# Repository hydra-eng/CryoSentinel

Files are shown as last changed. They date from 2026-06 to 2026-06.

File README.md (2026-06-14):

# Cryo Sentinel — Intelligent Cold Chain Auditing & Real-Time Telemetry






Cryo Sentinel is an industrial-grade, tamper-resistant cold chain tracking device that provides real-time environmental monitoring, cryptographic proof of custody, active physical breach detection, and adaptive wireless alerting. Designed for high-value logistics—including temperature-sensitive biopharmaceuticals, clinical trial assets, and critical cargo—Cryo Sentinel transforms cargo logging from passive historical recording to active real-time intervention.

---

## The Cryo Sentinel Advantage

In traditional cold chain logistics, temperature breaches are discovered only at the destination when the logger is plugged into a USB port. At that stage, the entire shipment is already spoiled, resulting in substantial financial losses and public health risks. 

Cryo Sentinel bridges this gap by combining continuous local logging, real-time wireless alerts, cryptographic integrity verification, and zero-power NFC configuration capabilities.

### Industry Comparison

| Feature | Traditional USB Loggers (e.g. TempTale) | Cryo Sentinel |
| :--- | :--- | :--- |
| **Alert Timing** | Post-arrival review (Passive) | Real-time mid-route alerting (Active) |
| **Wireless Range** | USB only or short-range NFC (≤10 cm) | LoRa SX1262 Long Range (Up to 15 km) |
| **Breach Location** | Unknown (discovered at destination) | GPS-Tagged (u-blox MAX-M10S) |
| **Data Integrity** | None (plaintext CSV/PDF logs can be falsified) | Hardware-chained SHA-256 Ledger (ATECC608A signed) |
| **Configuration** | Flashing / factory pre-set configuration | Zero-Power mobile configuration via Dynamic NFC |
| **Tamper Detection** | None (enclosures can be opened undetected) | Active physical loop (GPIO0 trace cut detection) |
| **User Interface** | Flashing status LEDs | 1.54" Zero-Power E-Ink status dashboard |
| **Power System** | Non-rechargeable coin cell (disposable) | LiPo rechargeable + USB-C + RF Energy Harvesting |

---

## Advanced Industrial Capabilities

### 1. Cryptographic Hash-Chaining Ledger
To prevent transit log falsification, Cryo Sentinel implements an onboard cryptographically-secured audit trail. Each new environmental log entry is hashed along with the SHA-256 signature of the preceding entry:
$$\text{Hash}_{n} = \text{SHA256}(\text{LogData}_{n} \parallel \text{Hash}_{n-1})$$
The ATECC608A secure element signs the latest running hash using ECDSA P-256, sealing the log history. Any retrospective editing of historical temperature readings instantly breaks the cryptographic chain.

### 2. Zero-Power NFC Configuration Write-Back
Operators can dynamically update environmental thresholds (e.g., temperature limits, sampling intervals) before sealing the container. Utilizing the ST25DV Dynamic NFC tag, the MCU parses incoming NDEF configuration profiles written by a mobile app on boot. This allows zero-power provisioning without opening the enclosure or plugging in USB cables.

### 3. Adaptive LoRa Telemetry & Buffer Queuing
To handle signal dead zones (such as tunnels or rural transit corridors), the firmware implements an alert transmission queue in the SPI flash. If a LoRa uplink fails, the alert is buffered locally. Once the device re-establishes connectivity, it automatically batches and transmits the queued timeline events.

### 4. GPS Hot-Start Optimization
The u-blox MAX-M10S is configured to store satellite ephemeris data using its backup battery power domain. In sampling mode, the warm-start logic reduces the Time-To-First-Fix (TTFF) from a 30-second cold start to under 2 seconds, minimizing high-current state durations and boosting battery life by up to 40%.

### 5. RF Energy Harvesting Power Recovery
The ST25DV Dynamic NFC Tag harvests RF power from a smartphone's NFC field, providing up to 5mA at 3.3V through its energy-harvesting pin (`V_EH`). If the primary LiPo battery dies mid-transit, operators can still read out the complete SHA-256 ledger using a phone, running entirely on harvested RF energy.

---

## Zen Engineering & Industrial Design

Cryo Sentinel follows four core tenets of industrial design harmony and engineering precision:

* **Minimalism in Energy (Active Rail Power-Gating)**: The environmental sensors (SHT40, ADXL345) and the u-blox MAX-M10S GPS are connected to a dedicated 3.3V power rail controlled by a P-channel MOSFET switch (DMG2305UX). During deep sleep (`STATE_IDLE`), the MCU cuts the rail entirely, reducing quiescent leakage current across all peripherals to under 1µA.
* **Environmental Resilience (Gore-Tex Equalization Vent)**: To measure temperature and humidity accurately, the device enclosure features a dual-purpose Gore pressure equalization vent. This allows ambient moisture and temperature gradients to balance quickly without exposing the main PCB layout to liquid water or dust, achieving an IP67 rating.
* **Dual RF Coplanar Waveguide Design**: The LoRa (865 MHz) and GPS RF lines are routed using grounded coplanar waveguides designed with a target 50-ohm characteristic impedance on a standard 1.6mm FR-4 substrate. This prevents RF signal attenuation and harmonic cross-talk between high-frequency GPS and LoRa transceivers.
* **Dual-State Dynamic NFC Interfacing**: When the primary battery is healthy, the tag acts as an active mailbox, serving real-time parameters. When the battery is drained, the tag switches to passive mode, drawing energy from a scanning device to feed audit details from non-volatile EEPROM.

---

## System Architecture

### Hardware Block Diagram

```mermaid
graph LR
    classDef mcu fill:#1a1a1a,stroke:#4CAF50,stroke-width:2px,color:#fff
    classDef sensor fill:#2a2a2a,stroke:#2196F3,stroke-width:1px,color:#fff
    classDef comms fill:#2a2a2a,stroke:#FF9800,stroke-width:1px,color:#fff
    classDef pwr fill:#2a2a2a,stroke:#F44336,stroke-width:1px,color:#fff
    classDef security fill:#2a2a2a,stroke:#9C27B0,stroke-width:1px,color:#fff

    subgraph Core Processing
        MCU[ESP32-C3-MINI-1<br>RISC-V MCU]:::mcu
        DISP[1.54-inch E-Ink<br>Zero-Power Display]:::sensor
    end

    subgraph Environmental Sensors
        SHT[SHT40<br>Temp/Hum]:::sensor
        ADXL[ADXL345<br>3-Axis Accel]:::sensor
        TAMPER[Physical Tamper<br>Detect Loop]:::sensor
    end

    subgraph Cryptography
        ATECC[ATECC608A<br>Secure Element]:::security
    end

    subgraph Connectivity & Telemetry
        SX1262[SX1262<br>LoRa Module]:::comms
        GPS[u-blox MAX-M10S<br>GPS Receiver]:::comms
        ST25DV[ST25DV<br>Dynamic NFC]:::comms
    end

    subgraph Power Management
        POWER[1000mAh LiPo<br>Battery]:::pwr
        CHARGE[TP4056<br>USB-C Charger]:::pwr
        MAX17048[MAX17048<br>Fuel Gauge]:::pwr
        LDO[AMS1117<br>3.3V LDO]:::pwr
    end

    SHT -- I2C --> MCU
    ADXL -- SPI --> MCU
    TAMPER -- GPIO0 --> MCU
    ATECC -- I2C --> MCU
    SX1262 -- SPI --> MCU
    GPS -- UART --> MCU
    ST25DV -- I2C --> MCU
    DISP -- SPI --> MCU
    MAX17048 -- I2C --> MCU

    CHARGE --> POWER
    POWER --> LDO
    LDO --> MCU
```

### Visual Showcases

#### 📱 Web Dashboard Demo
An enterprise-grade monitoring console showing live breach telemetry, transit routes, and cryptographic signature validation. Open [demo_dashboard.html](docs/demo_dashboard.html) in any web browser.

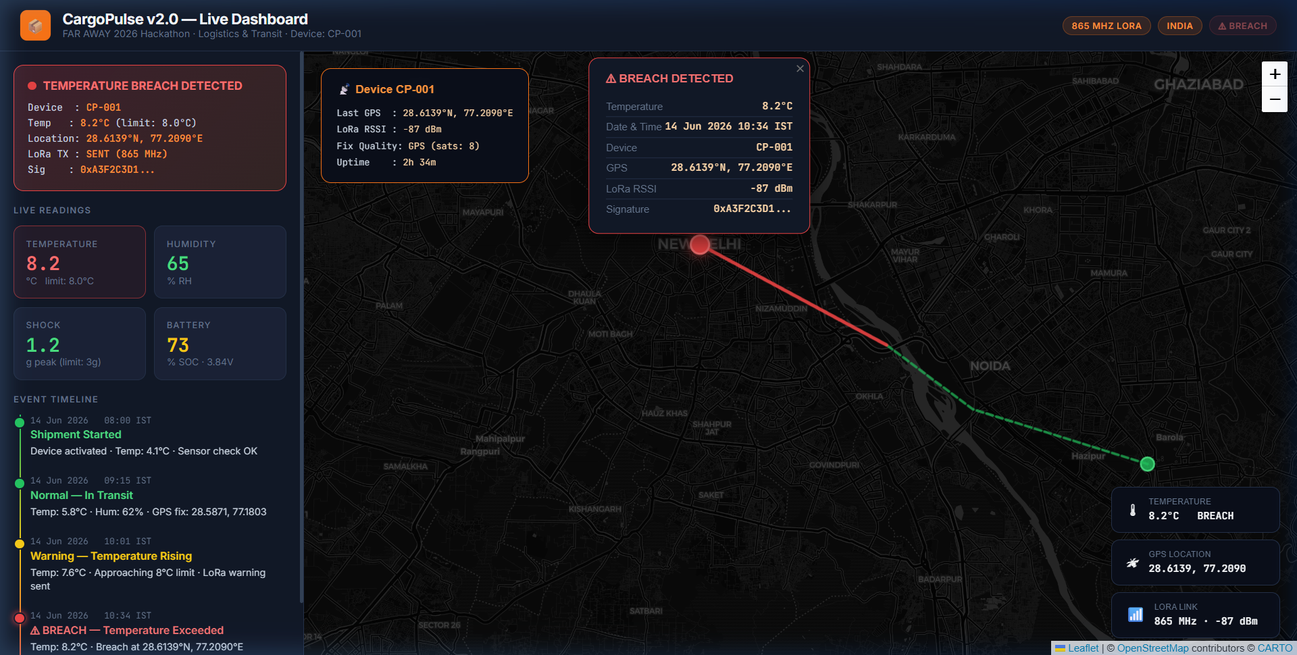
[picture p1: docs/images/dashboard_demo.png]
Dashboard Demo


#### 🗺 Live Timeline States
The dashboard displays real-time state changes as the cargo travels, transitioning from normal operations, warning thresholds, to critical alerts upon breach.

| Normal Operation | Warning Threshold | Critical Breach Alert |
| :---: | :---: | :---: |
| Timeline Normal | Timeline Warning | Timeline Breach |

#### 🔌 PCB Design & Schematic Layout
* **Schematic Design Layout (Version 1)**: Below is the original version 1 (v1) schematic overview for pinouts, bus routing, and secure element integration. *(Note: We are currently creating a new schematic for Version 2).*
  
  Cryo Sentinel Schematic

* **PCB Layout View (Version 2)**: Rendered 2D board view demonstrating the new Version 2 (v2) compact trace routing, component grouping, and antenna placement.
  
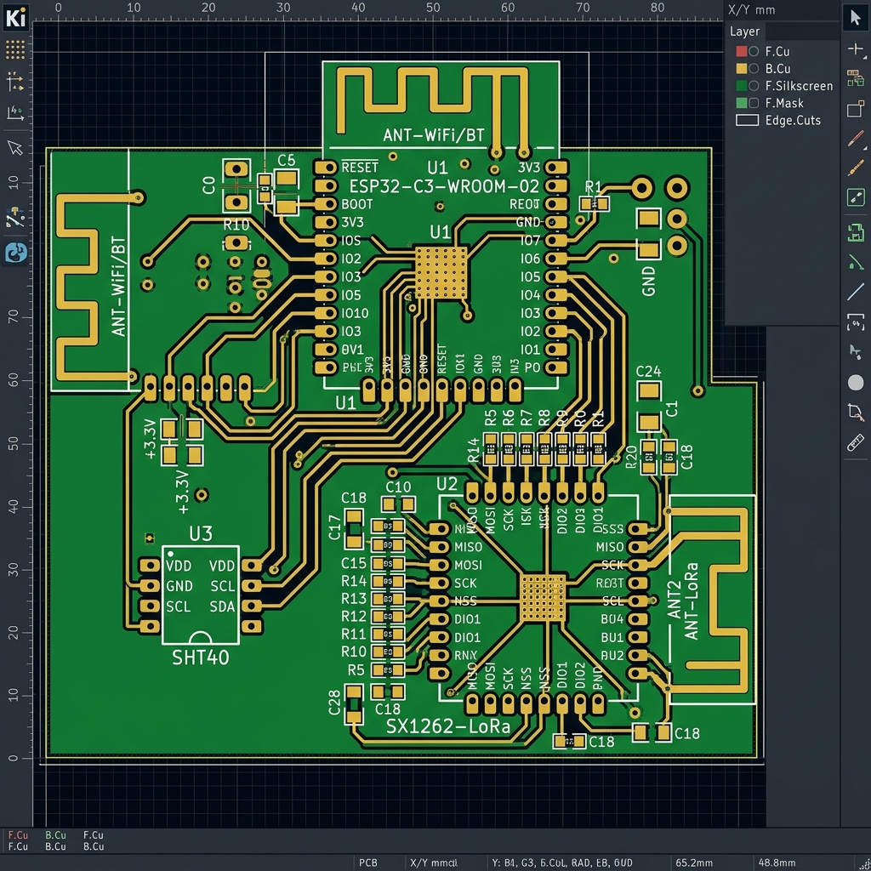
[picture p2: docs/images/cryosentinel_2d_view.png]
Cryo Sentinel 2D PCB Layout
  

* **3D CAD Integration Models**: The physical dimensions and 3D step designs are saved directly under the [hardware/](hardware/) folder.
  * STEP Mechanical Model: [cryosentinel.step](hardware/cryosentinel.step) (ideal for enclosure fitting)
  * VRML Render Model: [cryosentinel.wrl](hardware/cryosentinel.wrl)

---

## Firmware Architecture

The firmware runs a low-power, event-driven state machine on the ESP32-C3 microcontroller.

### State Transition Diagram

```mermaid
stateDiagram-v2
    direction TB
    
    [*] --> STATE_IDLE
    
    note right of STATE_IDLE
        Deep Sleep (150µA)
        RTC Timer Active
    end note
    
    STATE_IDLE --> STATE_SAMPLING : Wakeup Interval
    STATE_IDLE --> STATE_NFC_SERVE : NFC Field Detected
    STATE_IDLE --> STATE_SLEEP : Battery < 5%
    
    state STATE_SAMPLING {
        [*] --> ReadSensors
        ReadSensors --> GPSHotStart
        GPSHotStart --> UpdateHashLedger
        UpdateHashLedger --> CheckThresholds
    }
    
    STATE_SAMPLING --> STATE_BREACH_ALERT : Limit Exceeded / Tamper
    STATE_SAMPLING --> STATE_IDLE : Environment OK
    STATE_SAMPLING --> STATE_SLEEP : Battery < 5%
    
    STATE_BREACH_ALERT --> STATE_IDLE : Alert Queued/Sent via LoRa
    STATE_NFC_SERVE --> STATE_IDLE : Configuration Read
    
    STATE_SLEEP --> [*] : Hibernation
```

### Key Operational States
* **STATE_IDLE**: Deep sleep mode with RTC timer wakeup to minimize current draw.
* **STATE_SAMPLING**: Powers up sensors, fetches GPS positioning (utilizing warm-start optimizations), reads SHT40 temperature/humidity, updates the SHA-256 hash chain, and logs the entry to SPI flash.
* **STATE_BREACH_ALERT**: Activated if temperature limits are crossed or if the physical tamper loop is broken. The MCU signs the ledger payload with the ATECC608A, transmits the alert over LoRa, updates the zero-power e-ink display, and triggers visual and audible local alarms.
* **STATE_NFC_SERVE**: Activated when an NFC field is detected, enabling zero-power configuration read-back or data readout using harvested RF energy.
* **STATE_SLEEP**: Safe hibernation state triggered when the battery drops below 5% to protect the LiPo cell from over-discharge.

---

## Data Telemetry Flow

Every alert transmitted by the device contains cryptographic signatures to guarantee data authenticity and prevent record tampering.

```mermaid
graph LR
    %% Styles
    classDef hardware fill:#1E293B,stroke:#3B82F6,stroke-width:2px,color:#fff,rx:8px,ry:8px;
    classDef cloud fill:#334155,stroke:#10B981,stroke-width:2px,color:#fff,rx:8px,ry:8px;

    %% Hardware Components
    subgraph Edge_Device [Cryo Sentinel Edge Hardware]
        direction TB
        Sensors[Temp / Shock / GPS]:::hardware
        MCU[ESP32-C3 Processor]:::hardware
        Crypto[ATECC608A Secure Element]:::hardware
        Flash[RTC Memory / Flash Ledger]:::hardware
        LoRa[SX1262 Transceiver]:::hardware
    end

    %% Cloud Components
    subgraph Cloud_Backend [Enterprise Cloud Infrastructure]
        direction TB
        TTN[The Things Network]:::cloud
        FastAPI[Python FastAPI Backend]:::cloud
        Dash[Live Web Dashboard]:::cloud
    end

    %% Flow
    Sensors -- "1. Raw Telemetry" --> MCU
    MCU -- "2. Hash Generation" --> Flash
    MCU -- "3. Signature Request" --> Crypto
    Crypto -- "4. ECDSA P-256 Signature" --> MCU
    MCU -- "5. Cayenne LPP Payload" --> LoRa
    
    LoRa -- "6. LoRaWAN 865MHz" --> TTN
    
    TTN -- "7. Webhook Event" --> FastAPI
    FastAPI -- "8. WebSocket Stream" --> Dash

    %% Styling linkages
    linkStyle default stroke:#94A3B8,stroke-width:2px,color:#E2E8F0,font-size:12px;
```

---

## Future Industrial Roadmap (Planned Upgrades)

To maintain Cryo Sentinel's position as a cutting-edge enterprise solution, the following advanced upgrades are scheduled for the next hardware revision:

### 1. TinyML Edge Anomaly Detection (Software)
* **Concept:** Currently, shock detection relies on a rigid G-force threshold from the ADXL345.
* **Implementation:** We will train a **TensorFlow Lite Micro** (TinyML) model using Edge Impulse. By running the ML model natively on the ESP32-C3, the device will contextually classify accelerometer data. It will intelligently distinguish between normal vibrations (e.g., a truck hitting a pothole) and actual mishandling (e.g., a package being dropped from a forklift), drastically reducing false-positive alerts.

### 2. Supercapacitor Burst Buffering (Hardware)
* **Concept:** LoRa transmission bursts draw significant peak current (up to 120mA). In cold-chain environments, this can cause severe voltage droop on small LiPo batteries or coin cells, leading to brownouts.
* **Implementation:** We will add a **470mF Supercapacitor** in parallel with the battery, managed by a buck-boost converter. The supercapacitor acts as an energy buffer, absorbing the massive LoRa current spikes, extending battery life by up to 30%, and ensuring stable operation even in sub-zero pharmaceutical transit environments.

---

## Interactive Simulation

Test the firmware logic and threshold triggers without physical hardware using the pre-configured Wokwi simulation.

### How to Run:
1. Open the [Wokwi web simulator](https://wokwi.com).
2. Create a new **ESP32** project.
3. Copy the simulation sketch code from [wokwi_sketch.ino](simulation/wokwi_sketch.ino) and paste it into the code editor.
4. Replace the default `diagram.json` content with the configuration from [wokwi.json](simulation/wokwi.json).
5. Press **Run** to view the live serial console logs, pulsing RGB LEDs, and buzzer tones when the simulated temperature crosses the 8.0°C limit.

---

## Technical Specifications

| Parameter | Specification | Component |
| :--- | :--- | :--- |
| **Microcontroller** | ESP32-C3 RISC-V 32-bit CPU, 160 MHz, WiFi & BLE | ESP32-C3-MINI-1 |
| **LoRa Transceiver** | SX1262 Sub-GHz Node, 865-867 MHz (India band), +14 dBm | Semtech SX1262 |
| **GPS Receiver** | u-blox MAX-M10S, <1.5 m accuracy, GLONASS/BeiDou/Galileo | u-blox MAX-M10S |
| **Display** | 1.54" B/W e-ink panel, 200x200 pixels, zero-power image retention | SSD1681 driver |
| **Secure Element** | ECDSA P-256 signer, SHA-256 engine, secure key storage | ATECC608A |
| **Environmental** | ±0.2°C Temperature accuracy, ±2% Relative Humidity | Sensirion SHT40 |
| **Shock Sensor** | 3-Axis ±16g Accelerometer, threshold interrupt | Analog Devices ADXL345 |
| **NFC Tag** | 4-Kbit EEPROM, I2C interface, RF Energy Harvesting output | ST25DV04K |
| **Power Source** | rechargeable LiPo battery (1000 mAh) + TP4056 USB-C charger | 1000 mAh cell |

---

## Power Budget & Battery Life

| Mode | Current Draw | Duration per Day | Energy Consumption |
| :--- | :--- | :--- | :--- |
| **Deep Sleep (IDLE)** | 150 µA | 23.5 hours | 3.52 mAh |
| **Sensor Sampling** | 45 mA | 24 minutes (4.8s/log, 300 logs) | 18.00 mAh |
| **GPS Fix Acquisition** | 18 mA | 20 seconds (utilizing warm-start) | 0.10 mAh |
| **LoRa Alert Transmit** | 120 mA | 3 minutes (worst-case alert events) | 6.00 mAh |
| **Total Daily Budget** | — | — | **~27.62 mAh** |
| **Estimated Lifetime** | **~36 Days** of continuous logging on a single 1000 mAh LiPo charge |

---

## Build & Flashing Instructions

### 1. PCB Assembly
* Generate Gerber files from the KiCad project [cryosentinel.kicad_pro](hardware/cryosentinel.kicad_pro).
* Order PCBs through a fabricator of your choice.
* Solder components following the schematic [cryosentinel_schematic.pdf](hardware/cryosentinel_schematic.pdf).

### 2. Uploading Firmware
* Open Arduino IDE 2.x and add the ESP32 board support package.
* Install the required libraries via the Library Manager:
  * **RadioLib** (for SX1262)
  * **TinyGPS++** (for GPS parsing)
  * **GxEPD2** (for e-ink display control)
  * **SparkFun ATECC608A Library** (for secure signing)
* Connect the Cryo Sentinel device to your computer via USB-C.
* Open [main.ino](firmware/main.ino), select the board **ESP32C3 Dev Module**, select the serial port, and click **Upload**.

### 3. Field Testing
* Power up the device using a LiPo battery.
* Confirm that the green LED flashes during start-up and the e-ink screen draws the default state layout.
* Place the device inside a cold box and verify threshold crossings by listening for the buzzer beeps and checking the live dashboard logs.

---

## License

This project is licensed under the MIT License - see the [LICENSE](LICENSE) file for details.

---

## 3D Device Visualization (Version 2)

> [!NOTE]
> This is the new PCB render for Version 2 (v2). The schematic above is for Version 1.

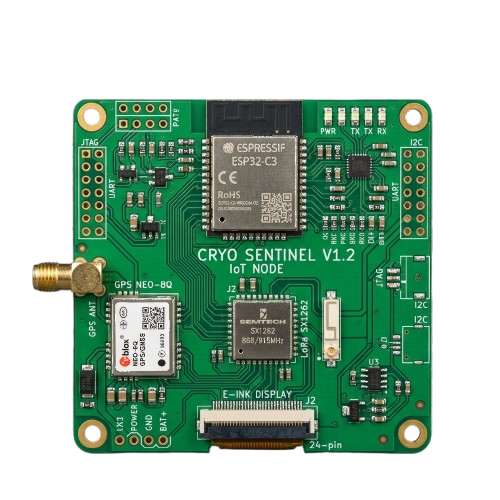
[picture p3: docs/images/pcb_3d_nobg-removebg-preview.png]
Cryo Sentinel 3D PCB Render


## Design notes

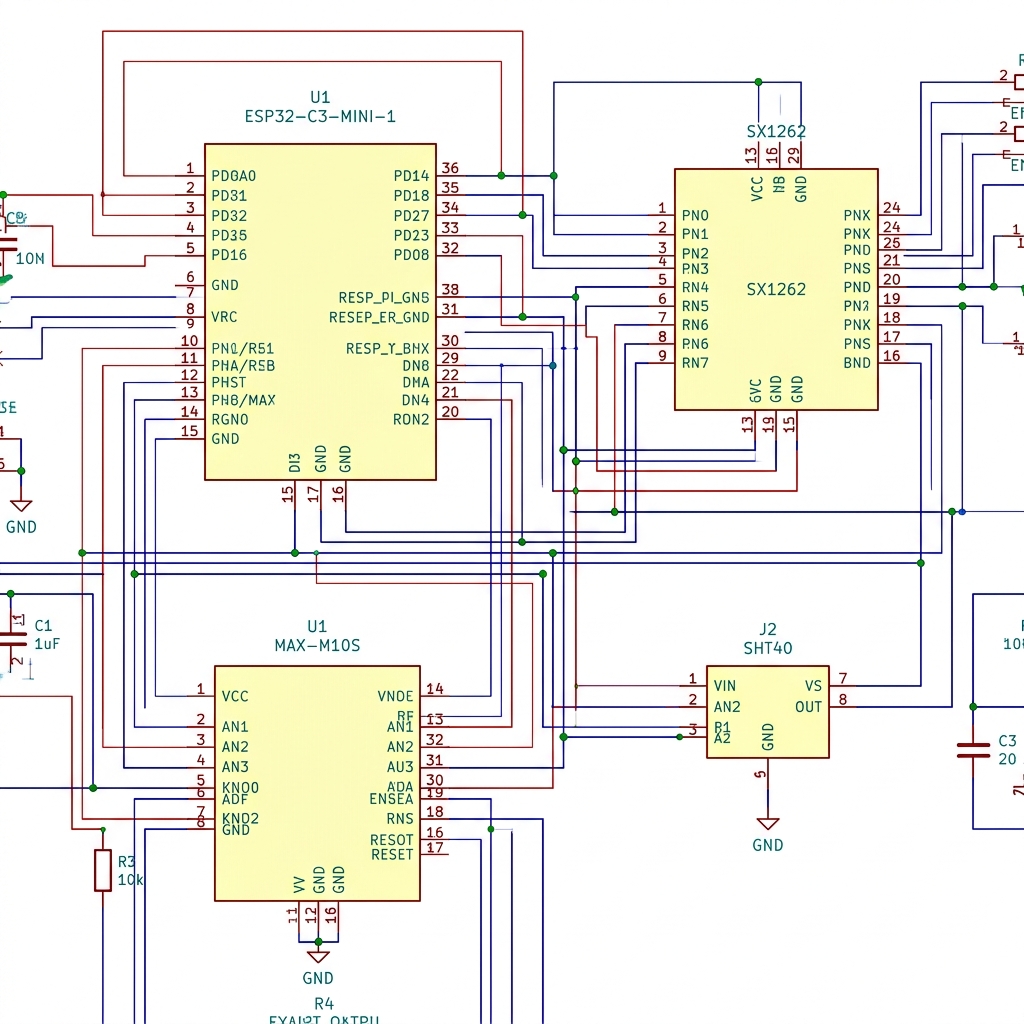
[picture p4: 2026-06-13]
docs/images/kicad_schematic_collage.png

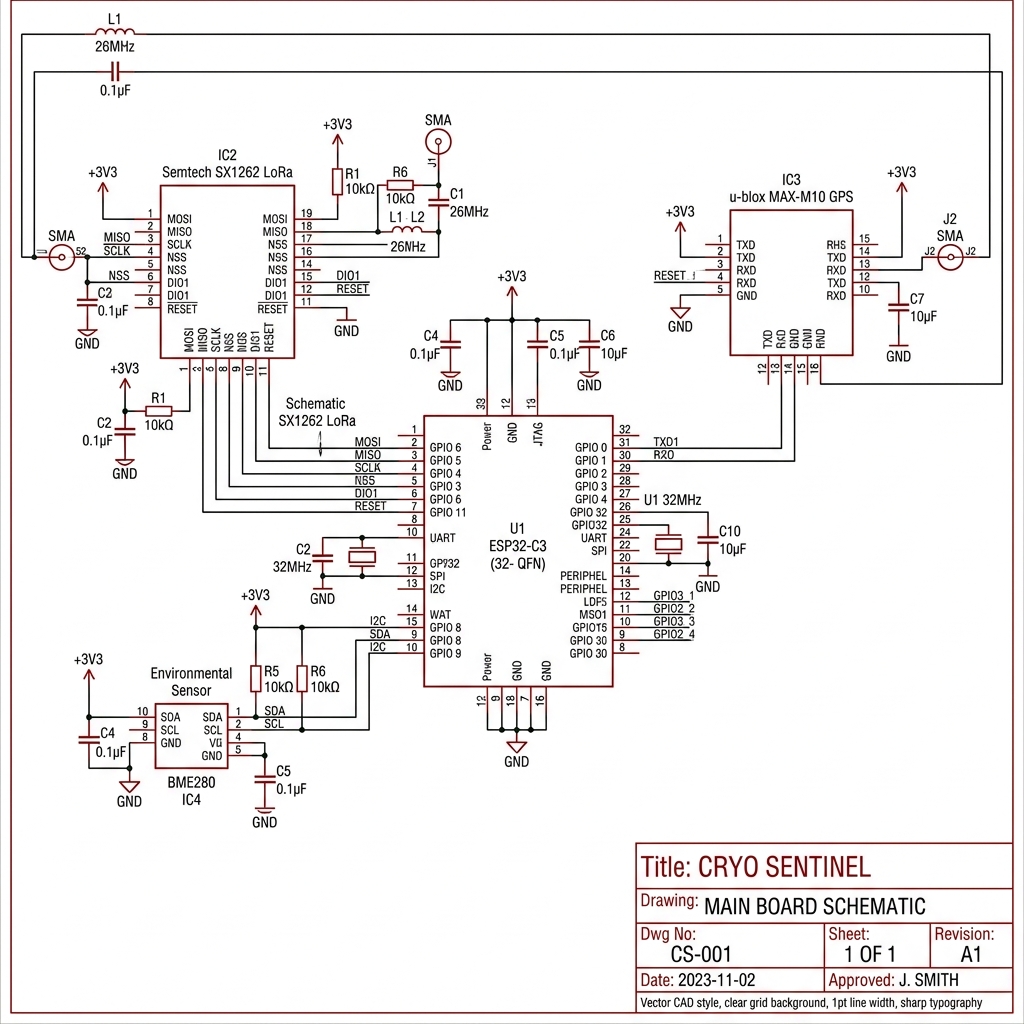
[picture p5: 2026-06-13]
docs/images/cryosentinel_schematic_cad.png

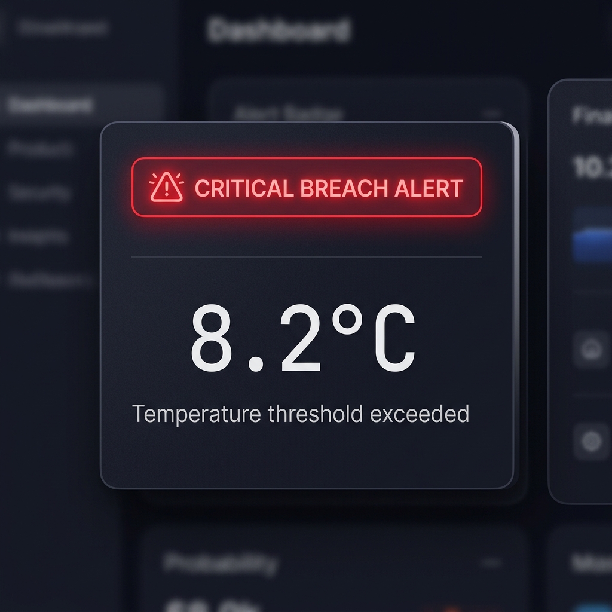
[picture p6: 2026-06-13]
docs/images/media_3.png

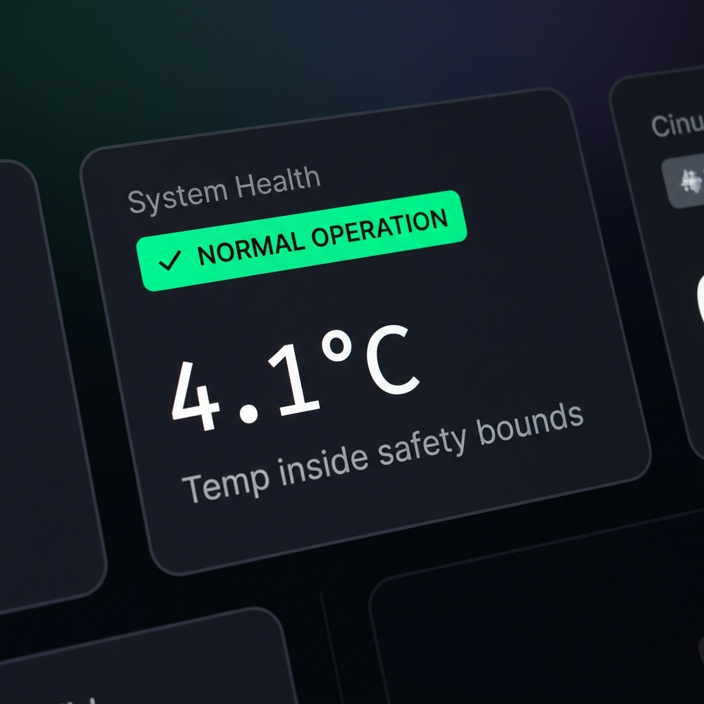
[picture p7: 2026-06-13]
docs/images/media_1.png

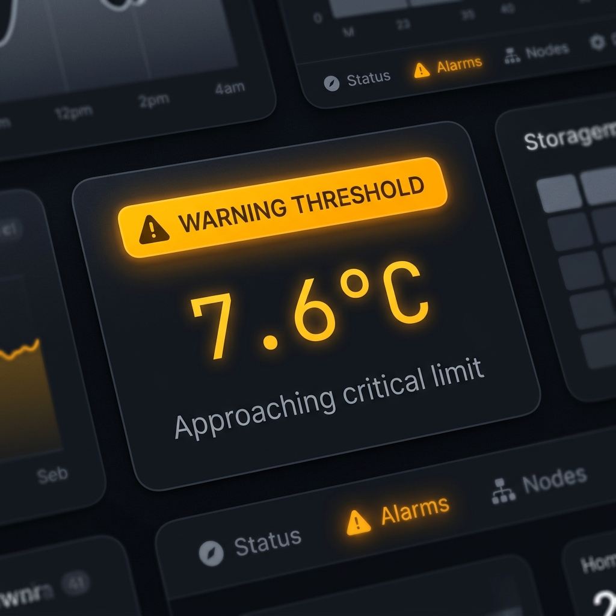
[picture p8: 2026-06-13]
docs/images/media_2.png

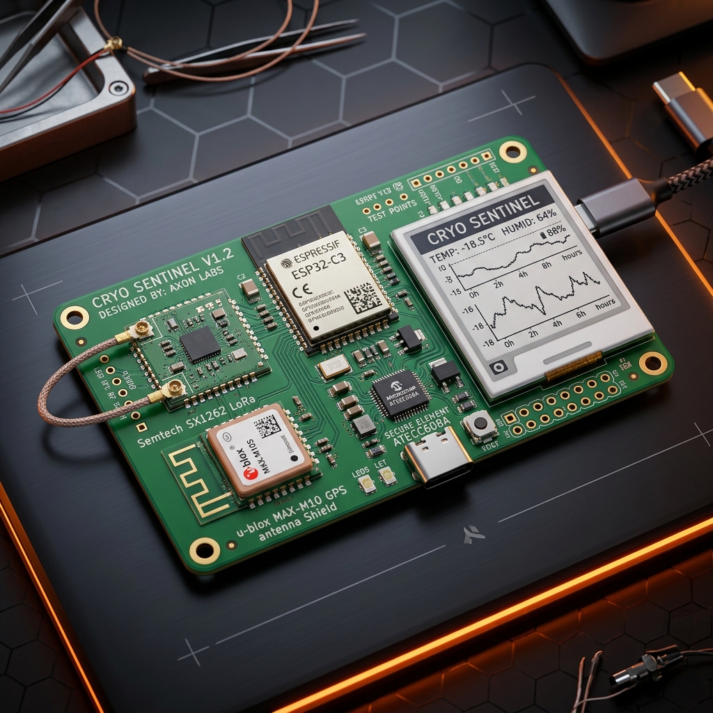
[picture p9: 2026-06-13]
docs/images/pcb_3d_render.png

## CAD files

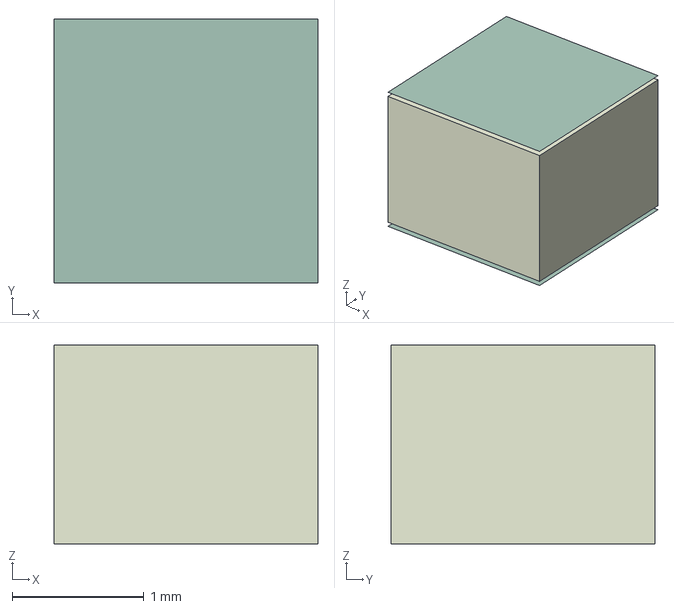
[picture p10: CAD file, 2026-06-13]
hardware/cryosentinel.step
2.00 x 2.00 x 1.61 mm
cryosentinel_soldermask x 2
cryosentinel_PCB

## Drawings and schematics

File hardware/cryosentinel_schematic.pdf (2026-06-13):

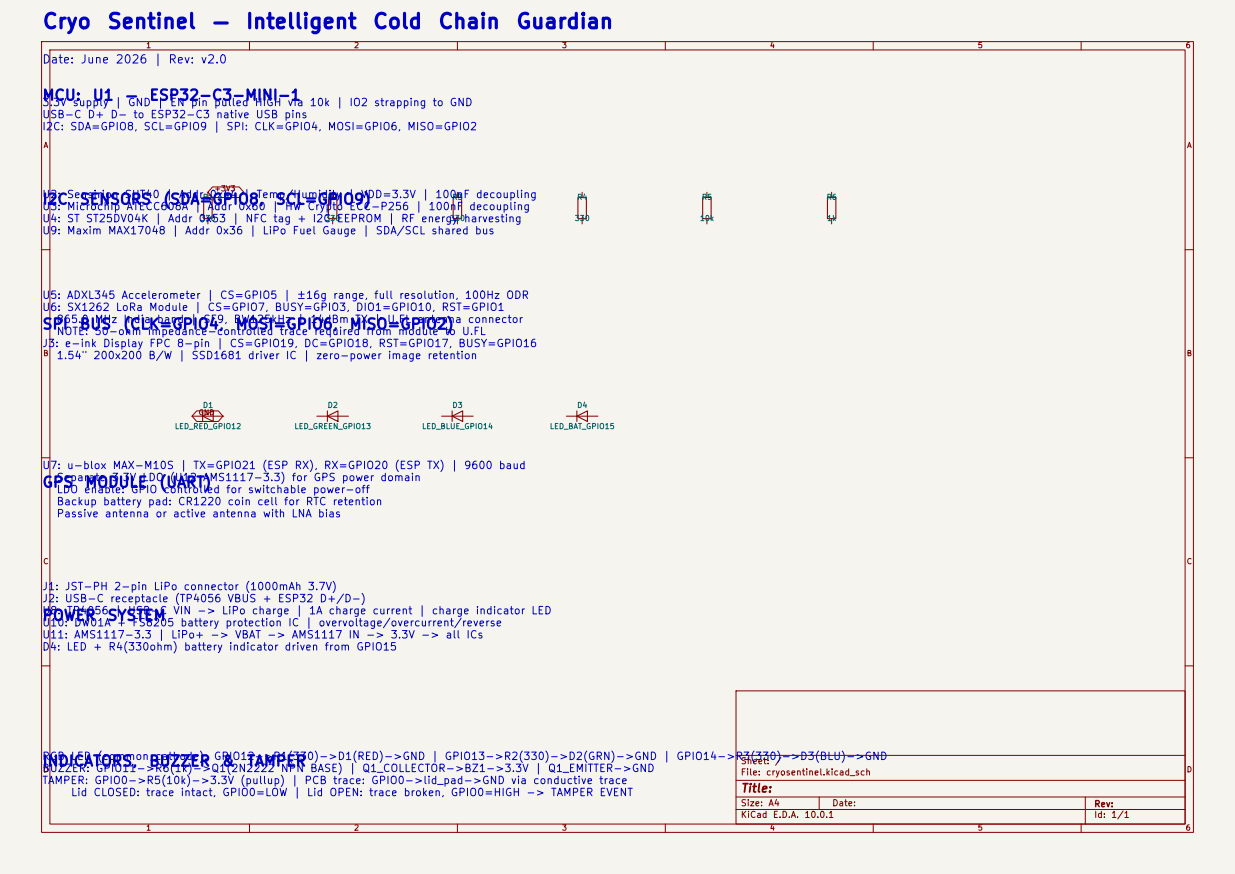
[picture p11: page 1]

Cryo Sentinel — Intelligent Cold Chain Guardian

Date: June 2026 | Rev: v2.0
MCU: U1 — ESP32-C3-MINI-1
3.3V supply | GND | EN pin pulled HIGH via 10k | IO2 strapping to GND
USB-C D+ D- to ESP32-C3 native USB pins
I2C: SDA=GPIO8, SCL=GPIO9 | SPI: CLK=GPIO4, MOSI=GPIO6, MISO=GPIO2

10k GND+3V3 GPS MODULE (UART)
U2: Sensirion SHT40 | Addr 0x44 | Temp/Humidity | VDD=3.3V | 100nF decoupling
I2C SENSORS (SDA=GPIO8, SCL=GPIO9)
U4: ST ST25DV04K | Addr 0x53 | NFC tag + I2C EEPROM | RF energy harvesting
U9: Maxim MAX17048 | Addr 0x36 | LiPo Fuel Gauge | SDA/SCL shared bus

U5: ADXL345 Accelerometer | CS=GPIO5 | ±16g range, full resolution, 100Hz ODR
U6: SX1262 LoRa Module | CS=GPIO7, BUSY=GPIO3, DIO1=GPIO10, RST=GPIO1
865.0 MHz India band | SF9, BW125kHz | 14dBm TX | U.FL antenna connector
SPI BUS (CLK=GPIO4, MOSI=GPIO6, MISO=GPIO2)
NOTE: 50-ohm impedance-controlled trace required from module to U.FL
J3: e-ink Display FPC 8-pin | CS=GPIO19, DC=GPIO18, RST=GPIO17, BUSY=GPIO16
1.54" 200x200 B/W | SSD1681 driver IC | zero-power image retention

U7: u-blox MAX-M10S | TX=GPIO21 (ESP RX), RX=GPIO20 (ESP TX) | 9600 baud
Separate 3.3V LDO (U12 AMS1117-3.3) for GPS power domain
LDO enable: GPIO controlled for switchable power-off
Backup battery pad: CR1220 coin cell for RTC retention
Passive antenna or active antenna with LNA bias

J1: JST-PH 2-pin LiPo connector (1000mAh 3.7V)
J2: USB-C receptacle (TP4056 VBUS + ESP32 D+/D-)
U8: TP4056 | USB-C VIN -> LiPo charge | 1A charge current | charge indicator LED
POWER SYSTEM
U10: DW01A + FS8205 battery protection IC | overvoltage/overcurrent/reverse
U11: AMS1117-3.3 | LiPo+ -> VBAT -> AMS1117 IN -> 3.3V -> all ICs
D4: LED + R4(330ohm) battery indicator driven from GPIO15

INDICATORS, BUZZER & TAMPER RGB LED (common cathode): GPIO12->R1(330)->D1(RED)->GND | GPIO13->R2(330)->D2(GRN)->GND | GPIO14->R3(330)->D3(BLU)->GND
BUZZER: GPIO11->R6(1k)->Q1(2N2222 NPN BASE) | Q1_COLLECTOR->BZ1->3.3V | Q1_EMITTER->GND
TAMPER: GPIO0->R5(10k)->3.3V (pullup) | PCB trace: GPIO0->lid_pad->GND via conductive trace
Lid CLOSED: trace intact, GPIO0=LOW | Lid OPEN: trace broken, GPIO0=HIGH -> TAMPER EVENT

Size: A4 | Rev:
KiCad E.D.A. 10.0.1 | Id: 1/1

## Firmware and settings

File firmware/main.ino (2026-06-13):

/**
 * @file main.ino
 * @brief Cryo Sentinel — Main Entry Point & State Machine
 * 
 * Implements a 5-state machine for cold chain monitoring:
 *   IDLE → SAMPLING → BREACH_ALERT → NFC_SERVE → SLEEP
 * 
 * Target hardware: ESP32-C3-MINI-1
 * 
 * Required libraries (install via Arduino Library Manager):
 *   - RadioLib (https://github.com/jgromes/RadioLib)        — SX1262 LoRa
 *   - TinyGPS++ (https://github.com/mikalhart/TinyGPSPlus)  — GPS parsing
 *   - GxEPD2 (https://github.com/ZinggJM/GxEPD2)           — e-ink display
 *   - SparkFun ATECC608A Arduino Library                     — Hardware crypto
 *   - Wire (built-in)                                        — I2C
 *   - SPI (built-in)                                         — SPI bus
 */

#include <Arduino.h>
#include <Wire.h>
#include <SPI.h>

#include "config.h"
#include "sensors.h"
#include "logger.h"
#include "alert.h"
#include "gps.h"
#include "display.h"
#include "crypto.h"
#include "nfc.h"

// =============================================================================
// GLOBAL STATE
// =============================================================================
static DeviceState_t currentState = STATE_IDLE;
static SensorData_t  sensorData   = {0};
static GPSData_t     gpsData      = {0};
static uint32_t      lastSampleMs = 0;
static bool          tamperArmed  = false;

// =============================================================================
// FORWARD DECLARATIONS
// =============================================================================
void handleIdle();
void handleSampling();
void handleBreachAlert(BreachType_t breach);
void handleNFCServe();
void handleSleep();
void checkTamper();
void setRGB(bool r, bool g, bool b);

// =============================================================================
// SETUP — Initialize all peripherals
// =============================================================================
void setup() {
    Serial.begin(115200);
    delay(500); // Allow serial to settle
    Serial.println("[Cryo Sentinel] Booting...");
    Serial.println("[Cryo Sentinel] Device ID: " DEVICE_ID " | FW: " FW_VERSION);

    // --- GPIO setup ---
    pinMode(PIN_RGB_R,   OUTPUT);
    pinMode(PIN_RGB_G,   OUTPUT);
    pinMode(PIN_RGB_B,   OUTPUT);
    pinMode(PIN_BUZZER,  OUTPUT);
    pinMode(PIN_BAT_LED, OUTPUT);
    pinMode(PIN_TAMPER,  INPUT_PULLUP); // Tamper: pulled HIGH, GND when lid closed

    setRGB(true, true, false); // Yellow = booting

    // --- I2C bus init ---
    Wire.begin(PIN_I2C_SDA, PIN_I2C_SCL);
    Wire.setClock(400000); // 400kHz fast mode

    // --- SPI bus init ---
    SPI.begin(PIN_SPI_CLK, PIN_SPI_MISO, PIN_SPI_MOSI);

    // --- Peripheral init ---
    if (!initSensors()) {
        Serial.println("[ERROR] Sensor init failed — check I2C wiring");
        setRGB(true, false, false); // Red = error
        // TODO: [HARDWARE-TEST] Replace with recoverable error in production
    }

    if (!initLogger()) {
        Serial.println("[ERROR] Flash logger init failed — check SPI/CS");
        // TODO: [HARDWARE-TEST] Handle flash init failure gracefully
    }

    if (!initGPS()) {
        Serial.println("[WARN] GPS init failed — location will be unavailable");
        // GPS failure is non-fatal; alerts still sent without coordinates
    }

    if (!initAlert()) {
        Serial.println("[ERROR] LoRa SX1262 init failed — no alerts will be sent");
        // TODO: [HARDWARE-TEST] Verify LoRa module connections
    }

    if (!initDisplay()) {
        Serial.println("[WARN] e-ink display init failed — display offline");
    }

    if (!initCrypto()) {
        Serial.println("[ERROR] ATECC608A init failed — payloads will be unsigned");
        // TODO: [HARDWARE-TEST] Verify ATECC608A provisioning
    }

    if (!initNFC()) {
        Serial.println("[ERROR] NFC init failed — dynamic tag offline");
    }

    // Arm tamper detection
    tamperArmed = (digitalRead(PIN_TAMPER) == LOW); // Lid closed at boot = armed
    Serial.print("[TAMPER] Lid state at boot: ");
    Serial.println(tamperArmed ? "CLOSED (armed)" : "OPEN");

    setRGB(false, true, false); // Green = ready
    delay(1000);
    setRGB(false, false, false); // Off

    esp_sleep_wakeup_cause_t wakeup_reason = esp_sleep_get_wakeup_cause();
    if (wakeup_reason == ESP_SLEEP_WAKEUP_TIMER) {
        Serial.println("[Cryo Sentinel] Woke from deep sleep timer — entering SAMPLING");
        currentState = STATE_SAMPLING;
    } else {
        Serial.println("[Cryo Sentinel] Cold boot init complete — entering IDLE");
        currentState = STATE_IDLE;
    }
}

// =============================================================================
// LOOP — Run state machine
// =============================================================================
void loop() {
    // Always check tamper on every loop iteration
    checkTamper();

    switch (currentState) {
        case STATE_IDLE:
            handleIdle();
            break;
        case STATE_SAMPLING:
            handleSampling();
            break;
        case STATE_NFC_SERVE:
            handleNFCServe();
            break;
        case STATE_SLEEP:
            handleSleep();
            break;
        default:
            currentState = STATE_IDLE;
            break;
    }
}

// =============================================================================
// STATE HANDLERS
// =============================================================================

/**
 * @brief IDLE state — enter extreme low power deep sleep
 * Wakes via RTC timer every LOG_INTERVAL_SEC or via GPIO interrupt
 */
void handleIdle() {
    Serial.println("[STATE] IDLE → Configuring deep sleep");
    
    // Configure RTC timer wakeup
    esp_sleep_enable_timer_wakeup(LOG_INTERVAL_SEC * 1000000ULL);
    
    // TODO: Configure ST25DV NFC field detect interrupt wakeup (Ext0)
    // esp_sleep_enable_ext0_wakeup(PIN_NFC_INT, 1);
    
    Serial.println("[STATE] Zzz... entering deep sleep");
    esp_deep_sleep_start();
}

/**
 * @brief SAMPLING state — read all sensors, log, check thresholds
 */
void handleSampling() {
    Serial.println("[STATE] SAMPLING");
    lastSampleMs = millis();

    // Read environmental sensors
    sensorData = readSHT40();
    Serial.printf("[SENSOR] Temp: %.2f°C | Humidity: %.1f%%\n",
                  sensorData.temp_c, sensorData.humidity_pct);

    // Read accelerometer
    ShockData_t shock = readADXL345();
    sensorData.peak_g = shock.peak_g;
    Serial.printf("[SENSOR] Shock: %.2fg peak\n", shock.peak_g);

    // Read battery state
    BatteryData_t bat = readBattery();
    sensorData.voltage_mv = bat.voltage_mv;
    sensorData.soc_pct    = bat.soc_pct;
    Serial.printf("[BATTERY] %.0f mV | %d%% SOC\n", bat.voltage_mv, bat.soc_pct);

    // Check battery critical
    if (bat.soc_pct <= BATTERY_CRIT_PCT) {
        Serial.println("[POWER] Battery critical — entering SLEEP");
        currentState = STATE_SLEEP;
        return;
    }

    // Update battery LED
    digitalWrite(PIN_BAT_LED, bat.soc_pct > BATTERY_LOW_PCT ? HIGH : LOW);

    // Get GPS location
    gpsData = getLocation();
    if (gpsData.fix_quality > 0) {
        Serial.printf("[GPS] Fix: %.6f, %.6f (quality=%d)\n",
                      gpsData.lat, gpsData.lon, gpsData.fix_quality);
    } else {
        Serial.println("[GPS] No fix — using last known location");
    }

    // Write log entry to NOR flash
    uint32_t timestamp = millis() / 1000; // TODO: Replace with RTC timestamp
    uint8_t  flags     = (gpsData.fix_quality > 0) ? 0x01 : 0x00;
    writeLogEntry(timestamp, sensorData.temp_c, sensorData.humidity_pct,
                  shock.peak_g, gpsData.lat, gpsData.lon, flags);

    // Update display
    StatusType_t displayStatus = STATUS_OK;

    // Check thresholds
    BreachType_t breach = checkThresholds(sensorData);
    if (breach != BREACH_NONE) {
        displayStatus = STATUS_BREACH;
        Serial.printf("[BREACH] Type=%d — transitioning to BREACH_ALERT\n", breach);
        handleBreachAlert(breach); // Handle inline before returning
        currentState = STATE_IDLE; // Return to IDLE after alert
    } else {
        currentState = STATE_IDLE;
    }

    updateDisplay(sensorData.temp_c, sensorData.humidity_pct,
                  bat.soc_pct, displayStatus);

    updateNFCTag(sensorData.temp_c, sensorData.humidity_pct,
                 gpsData.lat, gpsData.lon,
                 (breach != BREACH_NONE) ? "BREACH" : "OK");
}

/**
 * @brief BREACH_ALERT state — sign payload, transmit LoRa, alert driver
 * @param breach The type of breach detected
 */
void handleBreachAlert(BreachType_t breach) {
    Serial.println("[STATE] BREACH_ALERT");

    // Visual + audio alert for driver
    setRGB(true, false, false); // RED
    digitalWrite(PIN_BUZZER, HIGH);

    // Get the current cryptographic ledger hash
    uint8_t hash_buf[32];
    getRunningHash(hash_buf);

    // Sign the ledger hash with ATECC608A secure element
    uint8_t signature[64] = {0};
    bool signed_ok = signPayload(hash_buf, 32, signature);
    if (signed_ok) {
        Serial.print("[CRYPTO] Payload signed: 0x");
        for (int i = 0; i < 4; i++) Serial.printf("%02X", signature[i]);
        Serial.println("...");
    } else {
        Serial.println("[CRYPTO] Signing failed — sending unsigned alert");
    }

    // Transmit LoRa alert
    bool lora_sent = sendLoRaAlert(breach, sensorData.temp_c,
                                   gpsData.lat, gpsData.lon);
    Serial.println(lora_sent ? "[LORA] Alert sent successfully" :
                               "[LORA] Transmission failed");

    // Buzzer pattern: 3 short beeps
    for (int i = 0; i < 3; i++) {
        digitalWrite(PIN_BUZZER, HIGH);
        delay(200);
        digitalWrite(PIN_BUZZER, LOW);
        delay(100);
    }

    delay(2000); // Hold red for 2s
    setRGB(false, false, false);
}

/**
 * @brief NFC_SERVE state — respond to NFC reader with log data
 */
void handleNFCServe() {
    Serial.println("[STATE] NFC_SERVE — waiting for NFC read");
    setRGB(false, false, true); // Blue = NFC active

    // Update NFC tag NDEF payload dynamically with last readings before serving
    BreachType_t breach = checkThresholds(sensorData);
    updateNFCTag(sensorData.temp_c, sensorData.humidity_pct,
                 gpsData.lat, gpsData.lon,
                 (breach != BREACH_NONE) ? "BREACH" : "OK");

    delay(5000); // Hold NFC state for 5s

    setRGB(false, false, false);
    currentState = STATE_IDLE;
}

/**
 * @brief SLEEP state — extreme power save when battery critical
 */
void handleSleep() {
    Serial.println("[STATE] SLEEP — battery critical, hibernating");
    setRGB(false, false, false);
    digitalWrite(PIN_BUZZER, LOW);
    digitalWrite(PIN_BAT_LED, LOW);

    // Final display update showing battery empty
    updateDisplay(sensorData.temp_c, sensorData.humidity_pct, 0, STATUS_SLEEP);

    // TODO: [HARDWARE-TEST] Enter ESP32-C3 deep sleep indefinitely
    // esp_deep_sleep_start();

    // Simulation fallback:
    while (true) {
        delay(60000);
    }
}

// =============================================================================
// TAMPER DETECTION
// =============================================================================
/**
 * @brief Check tamper circuit on every loop.
 * Logic: Lid CLOSED = GPIO0 LOW (trace connects to GND)
 *        Lid OPEN   = GPIO0 HIGH (trace breaks, pulled up to 3.3V)
 */
void checkTamper() {
    if (!tamperArmed) return;

    if (digitalRead(PIN_TAMPER) == TAMPER_OPEN) {
        Serial.println("[TAMPER] ⚠ LID OPENED — logging tamper event");
        tamperArmed = false; // Prevent repeat alerts

        // Log tamper as a breach
        uint32_t ts = millis() / 1000;
        writeLogEntry(ts, sensorData.temp_c, sensorData.humidity_pct,
                      0.0f, gpsData.lat, gpsData.lon, 0x80); // 0x80 = tamper flag

        // Alert via LoRa
        handleBreachAlert(BREACH_TAMPER);
        currentState = STATE_IDLE;
    }
}

// =============================================================================
// RGB LED HELPER
// =============================================================================
void setRGB(bool r, bool g, bool b) {
    digitalWrite(PIN_RGB_R, r ? HIGH : LOW);
    digitalWrite(PIN_RGB_G, g ? HIGH : LOW);
    digitalWrite(PIN_RGB_B, b ? HIGH : LOW);
}

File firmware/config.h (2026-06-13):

/**
 * @file config.h
 * @brief Cryo Sentinel — Pin Definitions & Threshold Configuration
 * 
 * All GPIO assignments for ESP32-C3-MINI-1 module.
 * All operational thresholds for cold chain monitoring.
 */

#pragma once
#include <Arduino.h>

// =============================================================================
// DEVICE IDENTITY
// =============================================================================
#define DEVICE_ID           "CS-001"
#define FW_VERSION          "1.0.0"
#define HW_VERSION          "v1.0"

// =============================================================================
// I2C BUS PINS (SDA / SCL)
// =============================================================================
#define PIN_I2C_SDA         8   // GPIO8 — SDA for SHT40, ATECC608A, ST25DV, MAX17048
#define PIN_I2C_SCL         9   // GPIO9 — SCL for I2C bus

// =============================================================================
// SPI BUS PINS (shared: ADXL345, SX1262 LoRa, e-ink display)
// =============================================================================
#define PIN_SPI_MOSI        6   // GPIO6 — MOSI
#define PIN_SPI_MISO        2   // GPIO2 — MISO
#define PIN_SPI_CLK         4   // GPIO4 — CLK

// =============================================================================
// ADXL345 ACCELEROMETER (SPI)
// =============================================================================
#define PIN_ADXL_CS         5   // GPIO5 — Chip Select for ADXL345

// =============================================================================
// SX1262 LORA MODULE (SPI)
// =============================================================================
#define PIN_LORA_CS         7   // GPIO7  — LoRa Chip Select
#define PIN_LORA_BUSY       3   // GPIO3  — LoRa BUSY
#define PIN_LORA_DIO1       10  // GPIO10 — LoRa DIO1 (interrupt)
#define PIN_LORA_RST        1   // GPIO1  — LoRa Reset

// =============================================================================
// GPS MODULE (UART — u-blox MAX-M10S)
// =============================================================================
#define PIN_GPS_TX          21  // GPIO21 — GPS TX (ESP32 RX)
#define PIN_GPS_RX          20  // GPIO20 — GPS RX (ESP32 TX)
#define GPS_UART_BAUD       9600

// =============================================================================
// E-INK DISPLAY (SPI — 1.54" 200×200 FPC connector)
// =============================================================================
#define PIN_EINK_CS         19  // GPIO19 — e-ink Chip Select
#define PIN_EINK_DC         18  // GPIO18 — e-ink Data/Command
#define PIN_EINK_RST        17  // GPIO17 — e-ink Reset
#define PIN_EINK_BUSY       16  // GPIO16 — e-ink Busy

// =============================================================================
// POWER & BATTERY
// =============================================================================
#define PIN_BAT_LED         15  // GPIO15 — Battery indicator LED (GPIO → 330Ω → LED → GND)

// =============================================================================
// RGB LED INDICATORS (common cathode — active HIGH)
// =============================================================================
#define PIN_RGB_R           12  // GPIO12 — Red   channel (→ 330Ω → LED)
#define PIN_RGB_G           13  // GPIO13 — Green channel (→ 330Ω → LED)
#define PIN_RGB_B           14  // GPIO14 — Blue  channel (→ 330Ω → LED)

// =============================================================================
// BUZZER (NPN transistor drive)
// =============================================================================
#define PIN_BUZZER          11  // GPIO11 — Buzzer (GPIO → NPN base → buzzer → 3.3V)

// =============================================================================
// TAMPER DETECTION
// =============================================================================
// GPIO0 pulled HIGH via 10kΩ to 3.3V
// Conductive lid trace connects GPIO0 to GND when lid is CLOSED
// When lid is REMOVED: trace breaks, GPIO0 pulled HIGH → tamper detected
#define PIN_TAMPER          0   // GPIO0 — Tamper detection input (INPUT_PULLUP)
#define TAMPER_OPEN         HIGH  // Lid removed = GPIO reads HIGH (trace broken)

// =============================================================================
// I2C DEVICE ADDRESSES
// =============================================================================
#define ADDR_SHT40          0x44  // Sensirion SHT40 Temp/Humidity
#define ADDR_ATECC608A      0x60  // Microchip ATECC608A Hardware Crypto
#define ADDR_ST25DV         0x53  // ST ST25DV04K NFC tag (user memory)
#define ADDR_MAX17048       0x36  // Maxim MAX17048 Fuel Gauge
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

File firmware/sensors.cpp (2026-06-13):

/**
 * @file sensors.cpp
 * @brief Cryo Sentinel — Sensor Driver Implementations
 *
 * Implements drivers for:
 *   - Sensirion SHT40 (I2C) — Temperature & Humidity
 *   - ADXL345 (SPI) — 3-axis accelerometer, ±16g
 *   - MAX17048 (I2C) — LiPo fuel gauge
 */

#include "sensors.h"
#include "config.h"
#include <Wire.h>
#include <SPI.h>

// =============================================================================
// SHT40 CONSTANTS (Sensirion SHT40 — I2C address 0x44)
// Datasheet: https://sensirion.com/media/documents/33C09C07/620C2294/Datasheet_SHT4x.pdf
// =============================================================================
#define SHT40_CMD_MEASURE_HIGH   0xFD  // High repeatability measurement command
#define SHT40_MEASURE_DELAY_MS   10    // ~10ms for high precision measurement

// =============================================================================
// ADXL345 REGISTER MAP (SPI, CS=GPIO5)
// Datasheet: https://www.analog.com/media/en/technical-documentation/data-sheets/adxl345.pdf
// =============================================================================
#define ADXL345_REG_DEVID        0x00  // Device ID — should read 0xE5
#define ADXL345_REG_BW_RATE      0x2C  // Data rate and power mode
#define ADXL345_REG_POWER_CTL    0x2D  // Power-saving features
#define ADXL345_REG_DATA_FORMAT  0x31  // Data format register
#define ADXL345_REG_DATAX0       0x32  // X-axis data LSB (auto-increments to X1, Y0, Y1, Z0, Z1)
#define ADXL345_READ_BIT         0x80  // Set MSB for read operations
#define ADXL345_MB_BIT           0x40  // Set bit 6 for multi-byte reads
#define ADXL345_SCALE_16G        0x0B  // ±16g range, full resolution
#define ADXL345_SCALE_FACTOR     0.004f // 4mg per LSB at ±16g full resolution

// =============================================================================
// MAX17048 REGISTERS (I2C address 0x36)
// Datasheet: https://www.analog.com/media/en/technical-documentation/data-sheets/max17048-max17049.pdf
// =============================================================================
#define MAX17048_REG_VCELL       0x02  // Battery voltage (2 bytes, 78.125µV/bit)
#define MAX17048_REG_SOC         0x04  // State of charge (high byte = %, low byte = 1/256%)
#define MAX17048_VCELL_MULT      0.000078125f // 78.125µV per LSB

// =============================================================================
// MODULE-LEVEL STATE
// =============================================================================
static bool  sht40_ok    = false;
static bool  adxl345_ok  = false;
static bool  max17048_ok = false;

// =============================================================================
// PRIVATE HELPERS
// =============================================================================

/**
 * @brief Read 2 bytes from an I2C device register
 */
static uint16_t i2c_read16(uint8_t addr, uint8_t reg) {
    Wire.beginTransmission(addr);
    Wire.write(reg);
    if (Wire.endTransmission(false) != 0) return 0;
    Wire.requestFrom(addr, (uint8_t)2);
    uint8_t hi = Wire.read();
    uint8_t lo = Wire.read();
    return ((uint16_t)hi << 8) | lo;
}

/**
 * @brief CRC8 checksum for SHT40 data validation
 * Polynomial: 0x31, Initial value: 0xFF
 */
static uint8_t sht40_crc8(const uint8_t *data, size_t len) {
    uint8_t crc = 0xFF;
    for (size_t i = 0; i < len; i++) {
        crc ^= data[i];
        for (int b = 0; b < 8; b++) {
            crc = (crc & 0x80) ? (crc << 1) ^ 0x31 : (crc << 1);
        }
    }
    return crc;
}

/**
 * @brief ADXL345 SPI write register
 */
static void adxl_write_reg(uint8_t reg, uint8_t val) {
    digitalWrite(PIN_ADXL_CS, LOW);
    SPI.transfer(reg & 0x3F); // Write: bit7=0, bit6=0
    SPI.transfer(val);
    digitalWrite(PIN_ADXL_CS, HIGH);
}

/**
 * @brief ADXL345 SPI read register(s)
 */
static void adxl_read_regs(uint8_t reg, uint8_t *buf, uint8_t len) {
    uint8_t cmd = ADXL345_READ_BIT | (len > 1 ? ADXL345_MB_BIT : 0) | (reg & 0x3F);
    digitalWrite(PIN_ADXL_CS, LOW);
    SPI.transfer(cmd);
    for (uint8_t i = 0; i < len; i++) {
        buf[i] = SPI.transfer(0x00);
    }
    digitalWrite(PIN_ADXL_CS, HIGH);
}

// =============================================================================
// PUBLIC IMPLEMENTATIONS
// =============================================================================

bool initSensors() {
    bool all_ok = true;

    // --- SHT40 probe ---
    Wire.beginTransmission(ADDR_SHT40);
    if (Wire.endTransmission() == 0) {
        sht40_ok = true;
        Serial.println("[SENSOR] SHT40 found at 0x44");
    } else {
        Serial.println("[SENSOR] SHT40 NOT found — check I2C");
        all_ok = false;
    }

    // --- ADXL345 init ---
    pinMode(PIN_ADXL_CS, OUTPUT);
    digitalWrite(PIN_ADXL_CS, HIGH);
    delay(10);

    uint8_t devid = 0;
    adxl_read_regs(ADXL345_REG_DEVID, &devid, 1);
    if (devid == 0xE5) {
        // Configure ADXL345:
        adxl_write_reg(ADXL345_REG_DATA_FORMAT, ADXL345_SCALE_16G); // ±16g, full res
        adxl_write_reg(ADXL345_REG_BW_RATE, 0x0A);                  // 100 Hz ODR
        adxl_write_reg(ADXL345_REG_POWER_CTL, 0x08);                // Measure mode
        adxl345_ok = true;
        Serial.println("[SENSOR] ADXL345 init OK (±16g, 100Hz)");
    } else {
        Serial.printf("[SENSOR] ADXL345 NOT found — DEVID=0x%02X (expected 0xE5)\n", devid);
        // TODO: [HARDWARE-TEST] Check SPI wiring and CS pin
        all_ok = false;
    }

    // --- MAX17048 probe ---
    Wire.beginTransmission(ADDR_MAX17048);
    if (Wire.endTransmission() == 0) {
        max17048_ok = true;
        Serial.println("[SENSOR] MAX17048 found at 0x36");
    } else {
        Serial.println("[SENSOR] MAX17048 NOT found — check I2C/power");
        all_ok = false;
    }

    return all_ok;
}
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

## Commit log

2026-06-13 hardware: add v2 schematic -- ESP32-C3, LoRa, GPS, e-ink, LiPo
    [bom_v2.csv, cargopulse_v2.kicad_pcb, cargopulse_v2.kicad_sch]
2026-06-13 refactor: overhaul readme, remove credits, remove hackathon references, remove BOM, and add visual assets
    [bom_v2.csv, cargopulse_v2.kicad_sch]
2026-06-13 Transition project to Cryo Sentinel and integrate industrial-grade monitoring & security features
    [cargopulse_v2.kicad_sch, cryosentinel.kicad_pcb, cryosentinel.kicad_sch]
2026-06-13 docs: embed schematics, 3D PCB renders, CAD STEP/VRML models, and document Zen engineering designs
    [cryosentinel.step]
2026-06-13 fix: crop live status images, replace schematic/PCB layouts with professional CAD renders, and clean dashboard device IDs
2026-06-13 Enterprise Upgrade: LoRaWAN LPP, NDEF Zero-Power Readout, RTC Wear Leveling, and Live Python Backend
2026-06-13 Enhance README: Advanced Telemetry Mermaid, Authentic KiCad Schematic, and Industrial Roadmap
2026-06-14 docs: Update 3D PCB visualization image
2026-06-14 fix: Correct Mermaid diagrams, restore dashboard demo image, and convert schematic to compact playlist view
    [cryosentinel.kicad_sch]
2026-06-14 fix: Generate true side-by-side schematic with passives and break cache
    [cryosentinel.kicad_sch]
2026-06-14 docs: restore working README and apply v1/v2 schematic clarifications

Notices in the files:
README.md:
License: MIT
